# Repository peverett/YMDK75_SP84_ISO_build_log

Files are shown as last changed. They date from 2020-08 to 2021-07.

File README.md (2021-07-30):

# YMDK 75% SP84 Split Keyboard Build Log

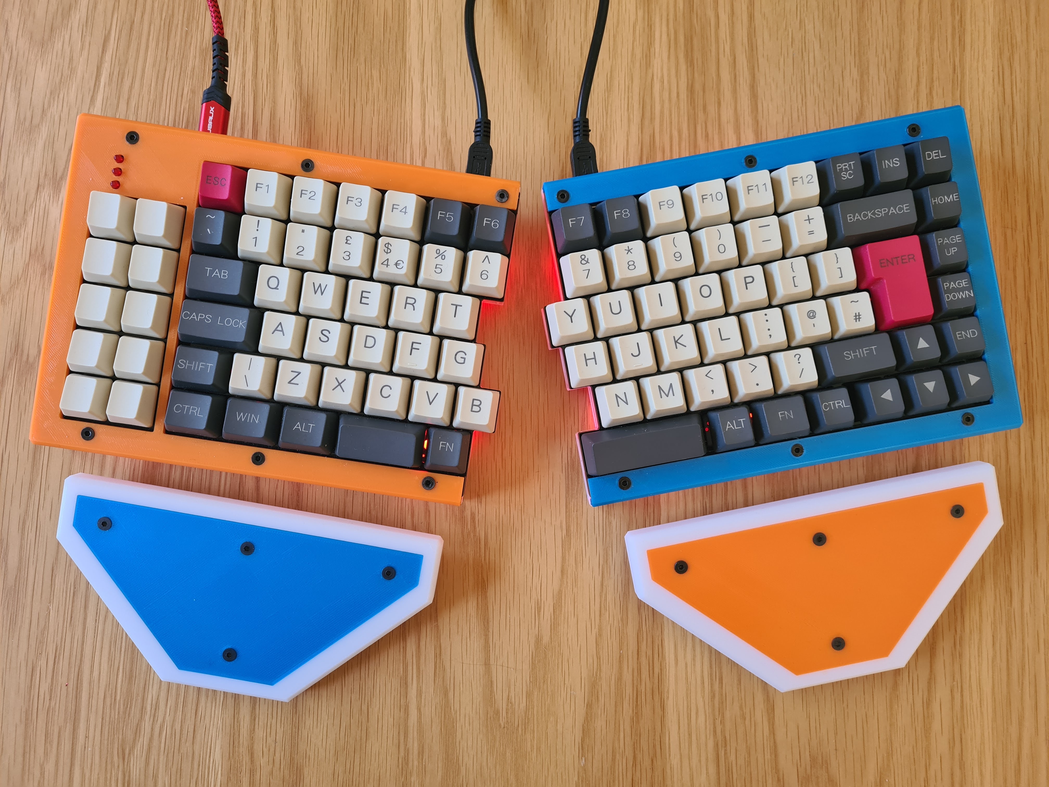
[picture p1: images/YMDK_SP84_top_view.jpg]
YMDK75-split

Final build with YMDK keycaps.

# Introduction
I decided to level up my Mechanical Keyboard skills by building my first kit.

When it comes to Mechanical Keyboards, I know what I like
* ISO UK over ANSI
* MX Browns or MX Clears

I've wanted a split keyboard for a while, but the need for an ISO UK layout put
me off a pure Ergonomic build. It's also very hard to find a custom split that 
isn't just ANSI.

The YMDK 75% Split Keyboard is similar to the V.EA layout. All images I found
on-line where ANSI layout but the specs state it can do ISO. It's also quite
in-expensive (as mechanical keyboards go), so I decided to give it a try.

Unfortunately, I didn't find any build instructions for the kit on-line and 
assumed they would come with the kit. I assumed incorrectly. Any one else
planning to build this kit, especially for ISO layout, may find this useful.

## Update: 2020-09-30
The Tai Hao ABS key caps, although very nice, didn't quite map to the keyboard 
layout, and the custom keys I received from WASD keyboards didn't blend well 
enough.

Then I found that I could buy the YMDK 96 84 key caps in Grey/Beige for ISO/ANSI
layout from Amazon UK. This set wasn't fully ISO UK, but I found the additional 
ISO keys for the YMDK set could be bought to make it a full ISO UK layout.

These key caps aren't as nice or as high quality as the Tao Hao ABS Doubleshot 
key cap set I originally bought, but they fit the layout perfectly and I am very 
happy with them.

## Custom Case Modification: 2020-12-27

The kit comes with six layers of laser cut acrylic that makes up the case, held
together with 10mm M3 screws and hexagonal brass stand-offs. However, the keyboard
underglow is very poor due to the black acrylic not reflecting the underside LED 
very well. I designed my own top and bottom layer to the each keyboard half. They
completely encapsulate the middle layers and use the same fixings to hold it 
together.

By using a white PLA for the bottom of the keyboard halves, the underglow is
significantly improved. The portal theme is almost accidental, I just used the
PLA colours I had available.

All the 3D models are in the [case_models](case_models/README.md) sub-folder for 
this repository, including some matching 3D printed wrist rests for each half.

## Parts

| Parts | Cost | Source |
|:---:|:---:|:---:|
| Split 75% SP84 DIY Kit (MX Browns) | £91.01  | AliExpress - YMDK Store |
| YMDK 96 84 ANSI ISO Keycap set (grey/beige) | £19.83  | Amazon UK |
| YMDK UK ISO Additional Keys Set (beige) | £10.45  | Amazon UK |

Some prices are converted from USD to GBP, and only accurate to the time of 
purchase.

### Split 75% SP84 DIY Kit

[Split 75% SP84 Acrylic Case Plate Underglow Fully Programmable PCB Stabilizers
ANSI ISO DIY Kit](https://www.aliexpress.com/i/33006060286.html) similar to VEA layout.
* There are several purchase options from bare PCB to fully assembled kit, with
a variety of switch options available too.
* I went with option 3 - Kit + 97 Cherry MX Brown switches + MX Stabilizers.
* You also need to buy 3 LED to go with the kit. I had some already, so
didn't bother.
* The kit doesn't include key caps but you can buy an YMDK key cap set for ANSI
and ISO, and a separate YMDK set for European ISO keys, including UK ISO.

Originally:
* [Tai Hao ABS Double Shot OEM Keycaps](https://www.aliexpress.com/item/32817770213.html) and [ISO Modifier Keycap kit](https://www.aliexpress.com/i/32962248699.html)
* Fortunately, YMDK sell the [extra keys for the SP84](https://www.aliexpress.com/item/4000873836738.html?spm=a2g0s.9042311.0.0.1a954c4d8baSSx) as a kit. Although they are only PBT, they are blank.
* The biggest issue I discovered is the right shift for ISO layout which is an R1 1x1.75 key.  
* I ended up buying the right shift and a couple of R1 1x1 keys for the bottom row from WASD. The postage was as expensive as the keys!

Updated 2020-09-30
* [YMDK 96 84 ANSI ISO Keycap set (gray/biege)](https://www.amazon.co.uk/gp/product/B079GZQFY6/ref=ppx_yo_dt_b_asin_title_o00_s00?ie=UTF8&psc=1) 
ISO layout but not quite ISO UK.
* [YMDK UK ISO Additional Keys Set (biege)](https://www.amazon.co.uk/gp/product/B086PDFN9S/ref=ppx_yo_dt_b_asin_title_o00_s00?ie=UTF8&psc=1) 
  for the missing ISO UK keys 

# Build Log

## YMDK 75% SP84 Keyboard kit.
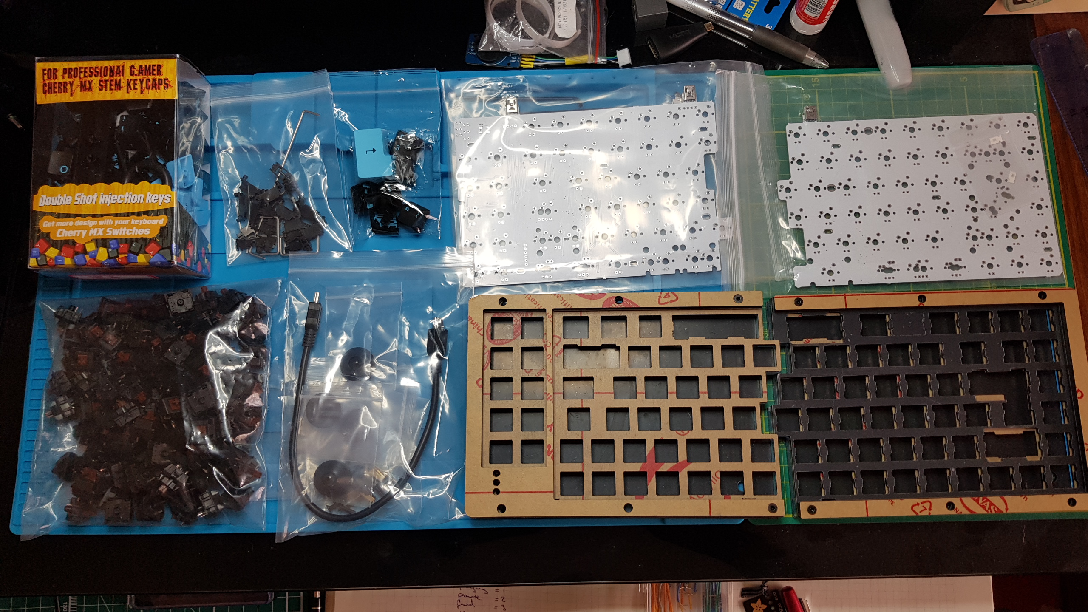
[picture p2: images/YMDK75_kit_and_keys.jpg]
Kit and Keys


The kit came in a plain box and was well protected with bubble wrap. The kit
contained:
* Two PCB boards (left and right hand side)
* The acrylic case parts, there are 6-layers to each side, with one being a 
clear acrylic layer for the under-glow.
* Fixings for the case consisting of
    * M3 10mm Countersunk hex bolts x 20 (should be 24)
    * 10mm brass standoffs female x 10 (should be 12)
* A bag of MX Stabilisers, enough for 5 stabilisers including the space-bar!
* 4 feet and bolts for feet
* USB-Standard-A to USB-Mini-B cable to connect the PC to the keyboard.
* USB-Mini-B to USB-Mini-B to connect the two keyboard halves.
* 96 x Cherry MX Brown switches.

Note: 
* The kit was missing 4-bolts and 2-standoffs for the case, but 
2-days after delivery they came in the post in a little box. 
* The kit doesn't include indicator LED, 3 are needed, I already had some but 
the YMDK shop has links to appropriate LED.
* The kit comes with 96 switches, which is the exact amount needed for the ISO 
layout.

## Testing the PCB

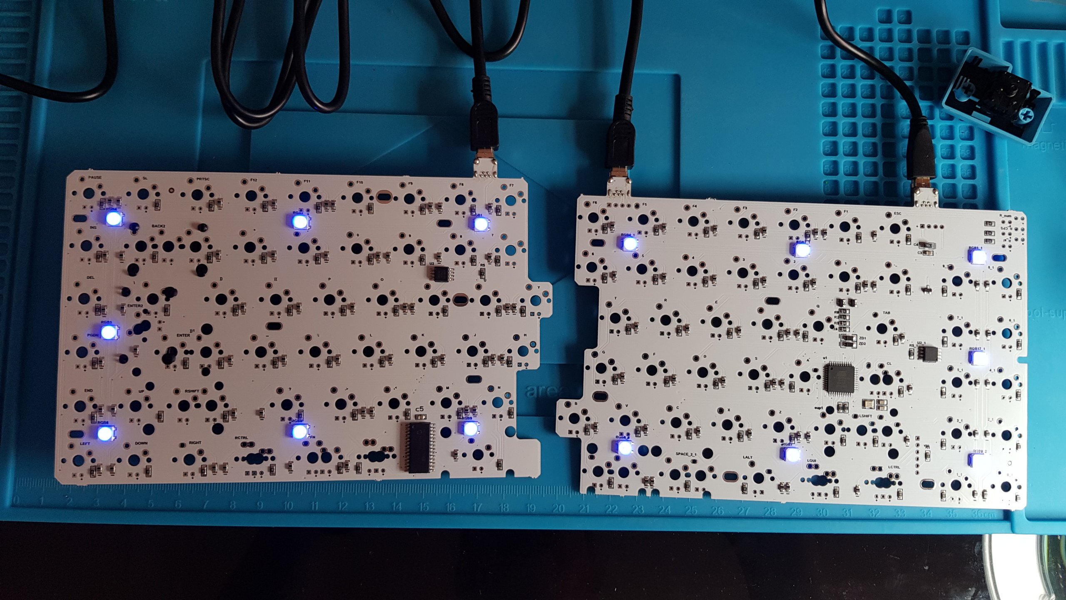
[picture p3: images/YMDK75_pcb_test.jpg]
pcb_test


Before starting I connected the PCB using the USB cables, you can see the 
under-glow LEDs are working.

## Right Side Stabilisers
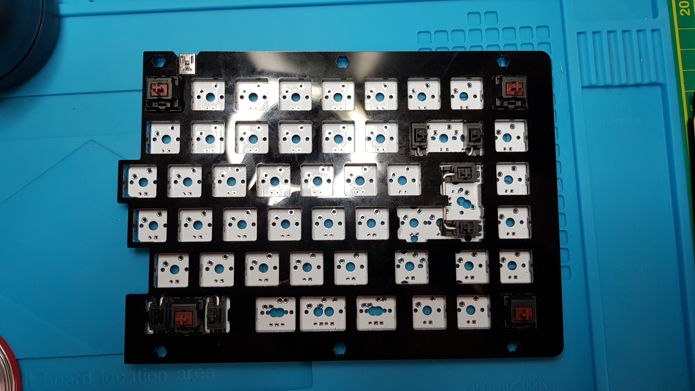
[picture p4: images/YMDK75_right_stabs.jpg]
right_side_stabs


Here you can see the Right side part of the keyboard with the Backspace, Return
and right side split Space-bar stabilisers. These are standard MX stabs.

* You have to fit the stabilisers before soldering any of the switches because the 
switches fit to the plate and hold the PCB in place.
* Three are needed, all the same size, even for the left side split space-bar key.
* The space-bar key stabiliser has to be fitted 'upside down' because it is at the
edge of the PCB and there isn't a full whole for the stabiliser leg. 
* I should have taken a picture before adding the base plate and four corner switches. I did for the left side though, so go see that.
* The right side shift is 1.75u, even for the ANSI layout. Let me tell you, that is a bugger to find a key cap for! 
(Updated 2020-09-30: Unless you buy the YMDK key cap set).

## Left Side Stabilisers

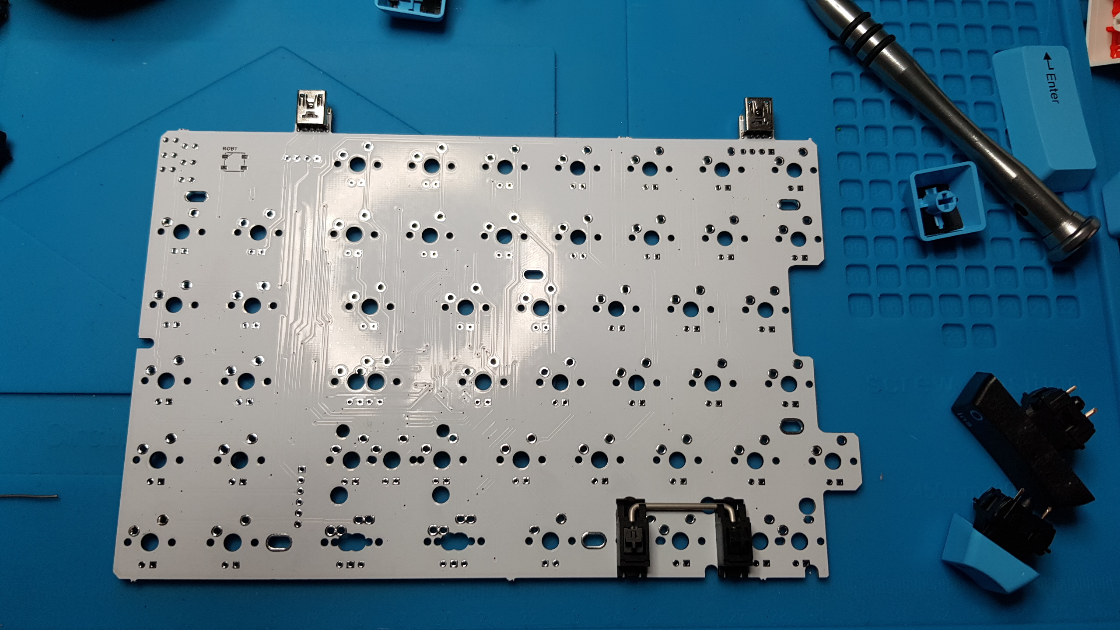
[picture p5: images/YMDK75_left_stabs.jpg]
left_side_stabs


I remembered to take the picture BEFORE fitting the plate and corner switches.
You can more clearly see the space-bar stabiliser is fitted upside down because it
is on the edge of the PCB. You can see, staggered to the right, two half-hole/notches, if you wanted the split further right. 

Because this is an ISO layout, no other stabilisers are necessary. 

## Left Side ISO keys
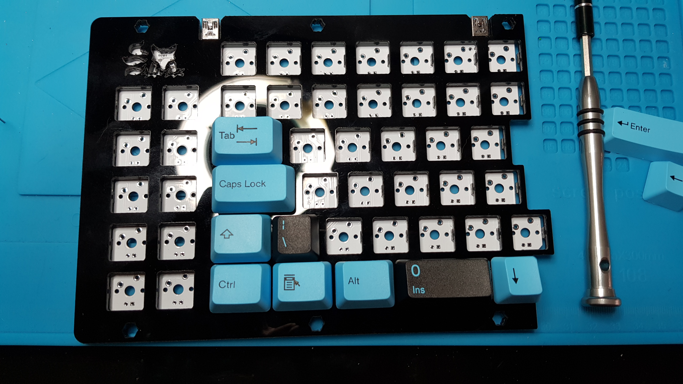
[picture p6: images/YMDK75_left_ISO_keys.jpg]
left_ISO_keys


Before soldering anything, I laid out the switches with the ISO keys to get 
the correct positions. 

As you can see the [0 Ins] key from the number-pad is the correct size for the
left size space key. I will replace it later when I get the keys from YMDK.

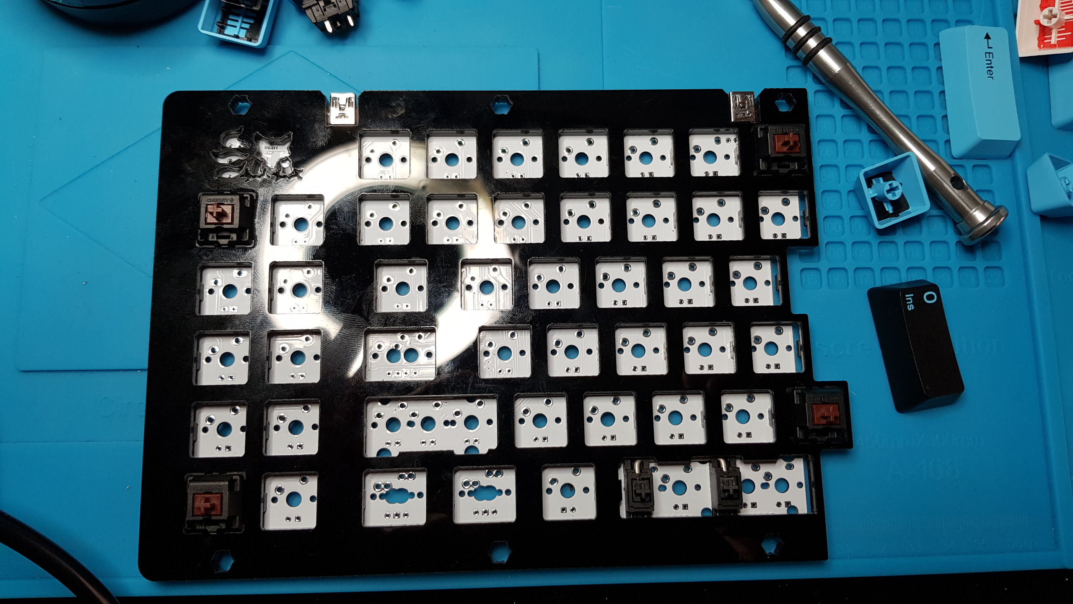
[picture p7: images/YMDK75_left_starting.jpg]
left_starting


As with the right side, two layers of acrylic make up the switch plate. The
switches fit tightly and click into each switch hole. Then, when soldered to
the PCB , the switched hold the plate to the PCB. There are no mounting screws
or holes in the PCB for this otherwise.

Following other guides, I soldered the corner switches first and then filled it
in. 

You can probably already see that the acrylic is a finger-print magnet.

## Fully Soldered and Naked

Here are the left and right side fully soldered and naked (without key caps), so
that you can clearly see the switch placement for the ISO layout. 

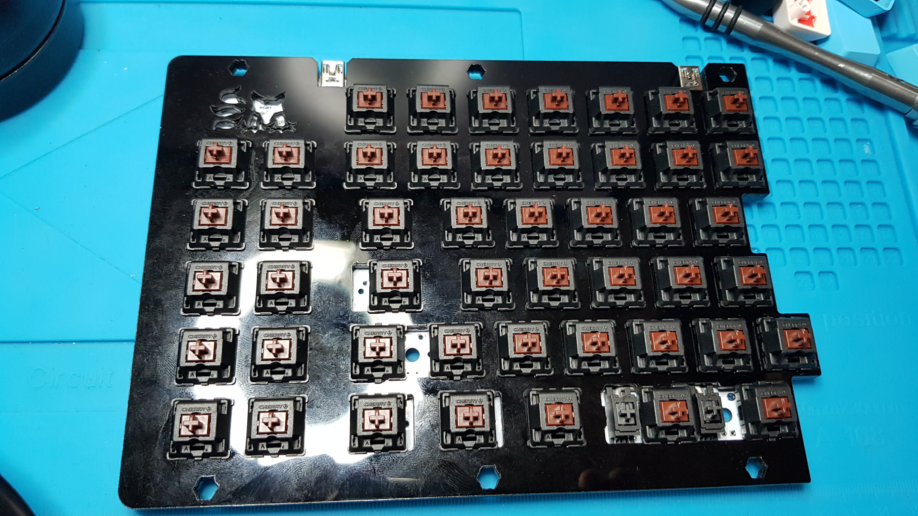
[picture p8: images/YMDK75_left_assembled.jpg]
left_assembled


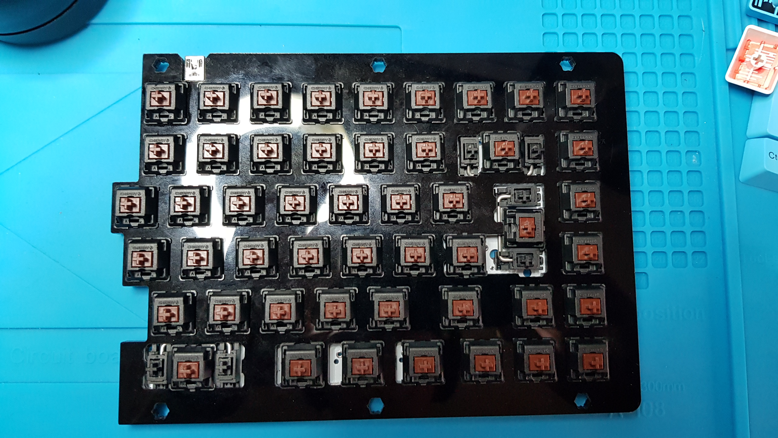
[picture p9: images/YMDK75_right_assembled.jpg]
right_assembled


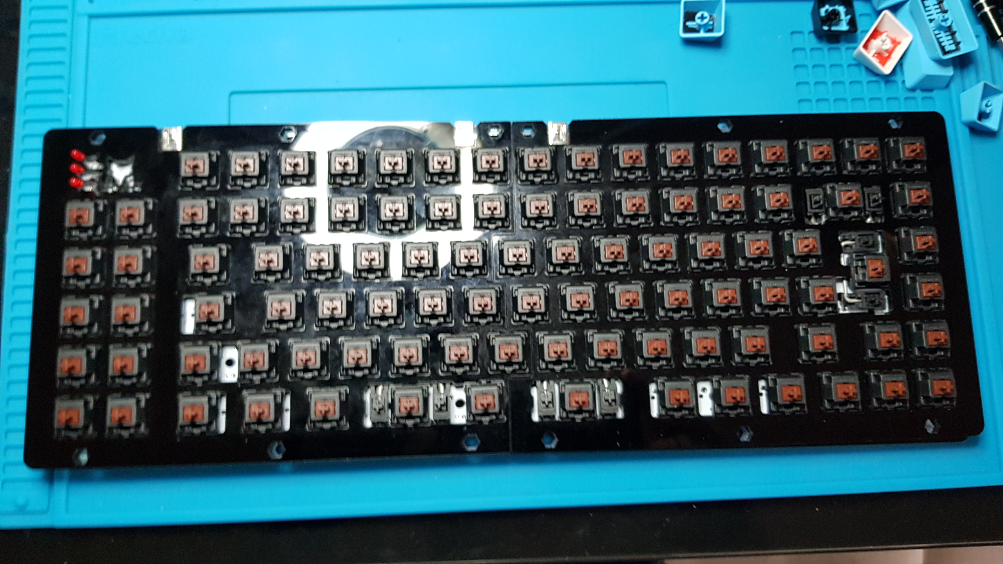
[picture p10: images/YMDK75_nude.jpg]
full_nude


## Fully Assembled

Here it is with all key caps in position. You can see that I have used some of
the num-pad keys on the bottom row for the split space-bar and R1 keys.

~~I'll add updates once the YMDK spare key kit comes.~~ In the end, I bought
the YMDK key cap set for this keyboard (see top picture).

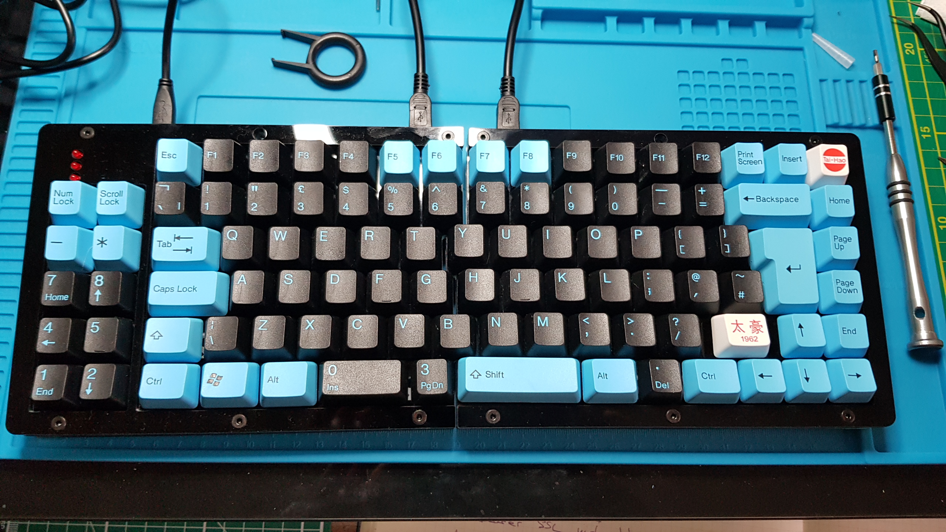
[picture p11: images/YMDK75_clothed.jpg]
fully_assembled


## Keyboard Layout 

Because, I've bastardized some of the keypad keys and because the documentation
is lacking, here are some layout diagrams for the YMDK 75% SP84 in ISO configuration.

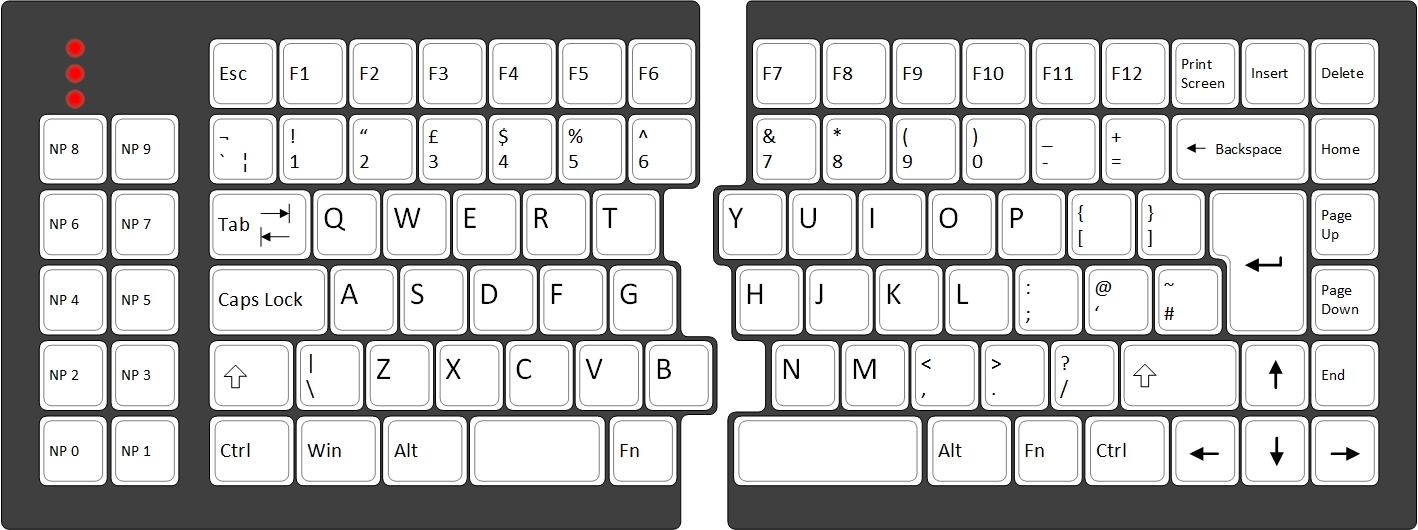
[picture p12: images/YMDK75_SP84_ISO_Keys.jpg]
ISO_Keys

Note that the extra keys on the left side are actually mapped to what would be
the numberpad on a full size keyboard. The numlock will change their function
but the standard keyboard software configuration doesn't map a numlock key.

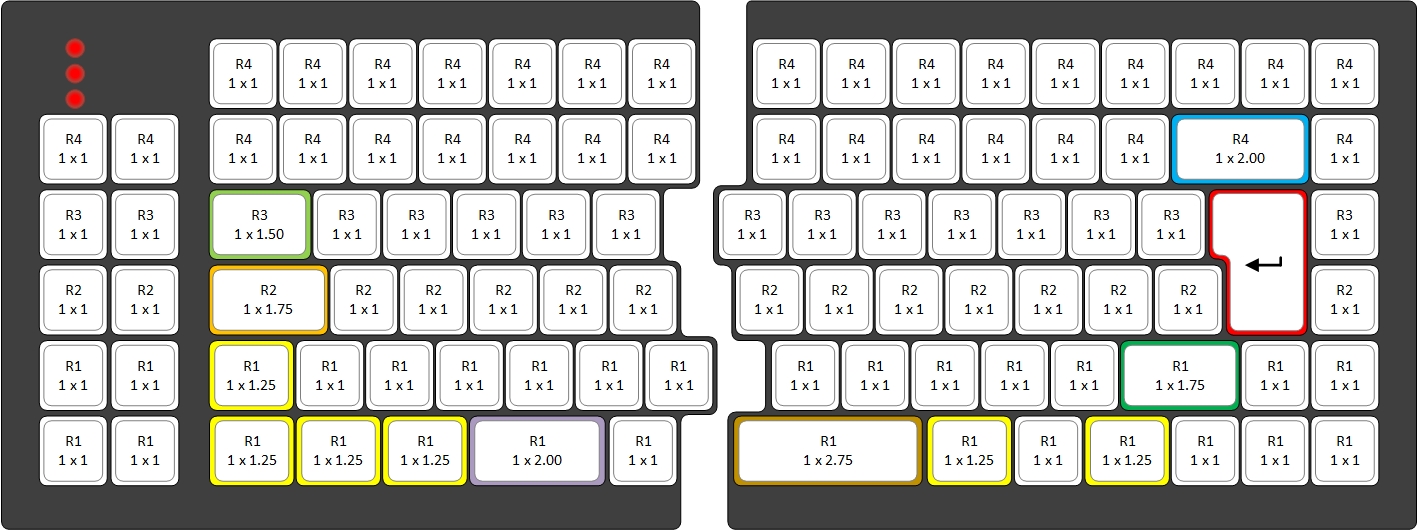
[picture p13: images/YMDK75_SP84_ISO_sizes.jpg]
ISO_Sizes

This is the same diagram but with the OEM key cap sizes. As previously stated 
that R1 1 x 1.75u Right Shift key is the hard one to source.

# Programming the Keyboard
I used the [Bootmapper Client](https://www.dropbox.com/s/3bn9flirkb49ahz/BootmapperClient.zip?dl=0)
application (downloaded from DropBox).

The software is little unpolished but serviceable.

I found two really good guides, linked below
* Drop - [Programming KBD Keyboards via Bootmapper Client](https://drop.com/talk/1392/programming-kbd-keyboards-via-bootmapper-client-tmk-guide-getting-added-soon-here)
* MecKey Alpha - [Guide on Bootmapper client](https://meckeyalpha.com/pages/guide-on-bootmapper-client)

# Conclusions

Overall, I am very happy with this keyboard and I am using it as my daily driver.
The cons listed below are minor, in my opinion. 

## Pros

* The kit was relatively inexpensive.
* It was a fun build for me, as the first keyboard I've built.
* I love the layout and using the split is very comfortable.
* Surprisingly, the multi-layered cut acrylic makes for a very solid, weighty 
keyboard.

## Cons
* Kit came with everything except key caps and three LEDs, but I feel that it could
have included the LEDs. 
* The acrylic is an absolute finger-print magnet.
* ~~YMDK sell key-cap sets (2 different colour schemes) for this, but not ISO~~.
* ~~The under-glow is very dim and can't be seen in normal lighting conditions.~~

## Update 2020-09-30: 

As you can see, some of the Cons turned out to be simple to resolve.
* The under-glow is configurable using the Bootmapper Client software, but by 
default is very dim.
* YMDK key caps for ISO and ANSI are available on Amazon UK, but it's not a full 
ISO UK set. There are additional YMDK ISO keys for the key caps that achieve a 
full ISO UK layout and I am very happy with that.

## Update 2020-11-09:

3D printing a case with a white translucent bottom half seems to significantly 
improve the underglow.

## Update 2020-12-27:

I completed the 3D printed case modifications, including wrist rests and added 
the 3D model files in this repository. See the [case_models](case_models/README.md)
folder for more details.

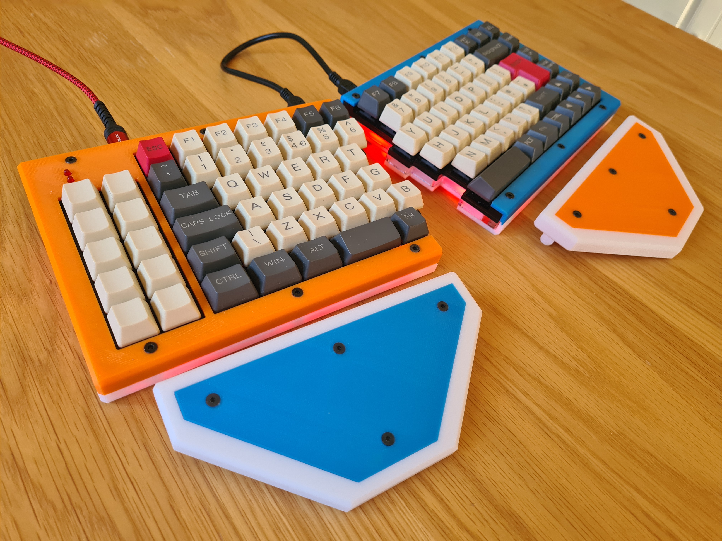
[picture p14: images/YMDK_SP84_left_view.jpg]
YMDK75-split

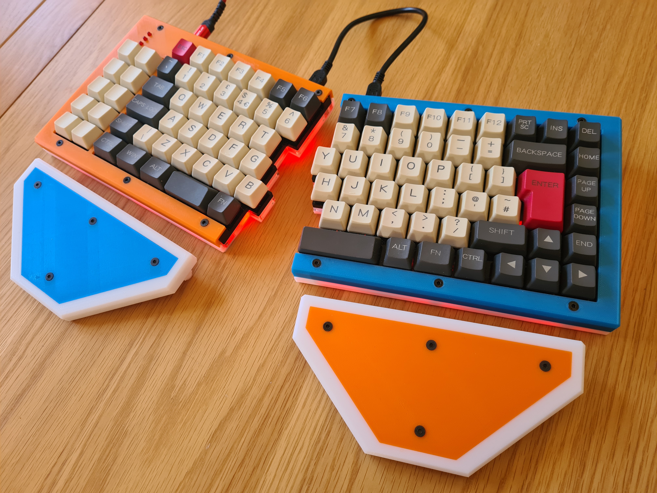
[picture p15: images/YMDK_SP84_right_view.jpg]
YMDK75-split


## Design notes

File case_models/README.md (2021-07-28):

# YMDK 75% SP84 Split Keyboard 3D Case Models

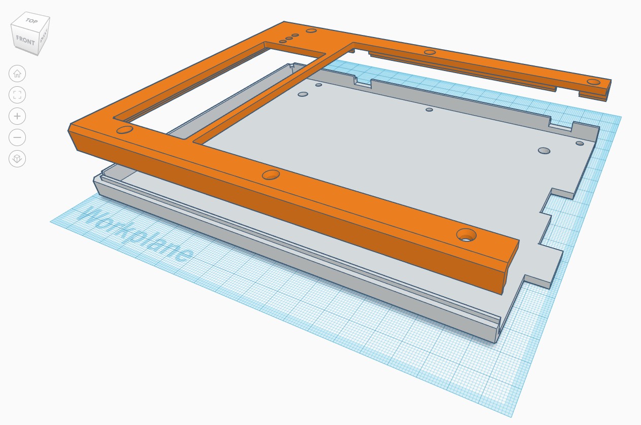
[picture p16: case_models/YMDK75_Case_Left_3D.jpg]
YMDK_3D_left

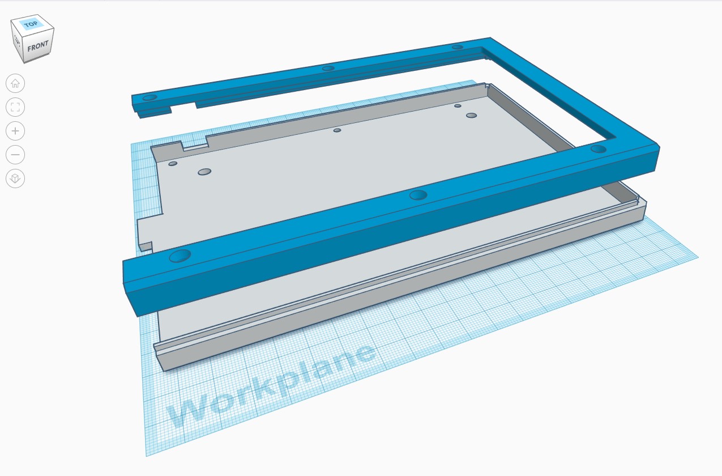
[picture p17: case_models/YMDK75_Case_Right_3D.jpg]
YMDK_3D_right


I used [TinkerCad](https://www.tinkercad.com) to design the case and wrist rest models, 
for a free, on-line 3D modeling tool it's basic but it gets the job done.

I have a Prusa MK3S Printer, and used the PrusaSlicer software to slice the models
for printing. 

### UPDATE: 2021-07-28
Added .SVG files for the keyboard case tops and bottoms.

## Print Settings

For printing, I used the basic default settings.

| Setting | Value |
|---|---|
| Print Setting | 0.15mm QUALITY MK3 |
| Filament | Prusa PLA |
| Printer | Original Prusa i3 MK3s  |
| Supports | None |
| Infil | 15% |

## Sliced Info

| Model | Print Time | Filament (g) | Filament (m) |
|:---:|:---:|:---:|:---:|
| Wrist-Rest-bottom.stl | 3h 59m 17s | 43.05 | 14.43 |
| Wrist-Rest-foot.stl | 41m 52s | 6.10 | 2.05 |
| Wrist-Rest-top.stl | 1h 22m 44s | 18.37 | 6.16 |
| YMDK-SP84-left-bottom.stl | 6h 14m 41s | 79.59 | 26.69 |
| YMDK-SP84-left-top.stl | 3h 17m 8s  | 29.73 | 9.97 |
| YMDK-SP84-right-bottom.stl | 6h 15m 48s | 80.13 | 26.87 |
| YMDK-SP84-right-top.stl | 3h 1m 26s  | 26.55 | 8.90 |

Don't forget to double up when printing the wrist wrest parts!

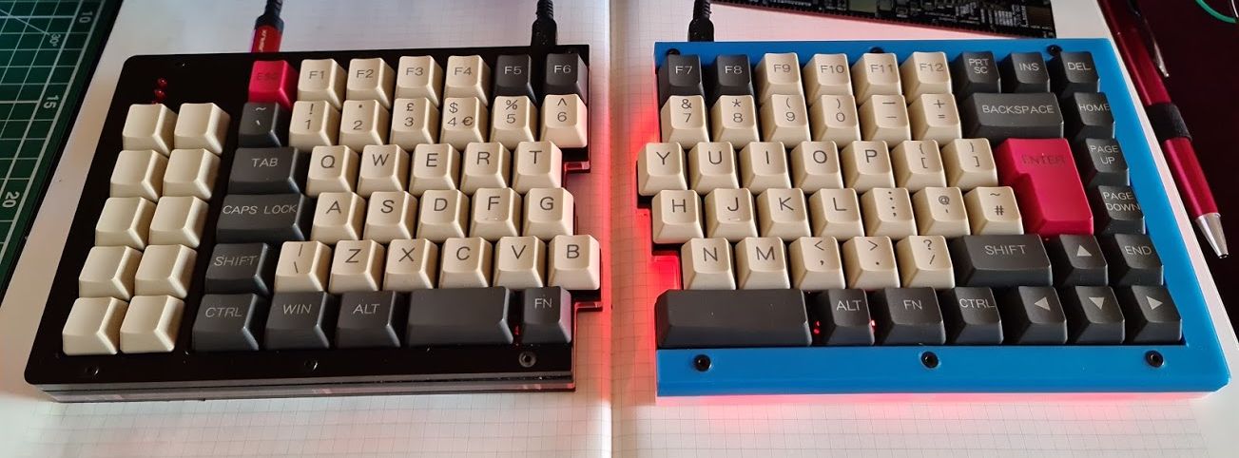
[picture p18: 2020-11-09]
images/YMDK_SP84_3d_case_comparison.jpg

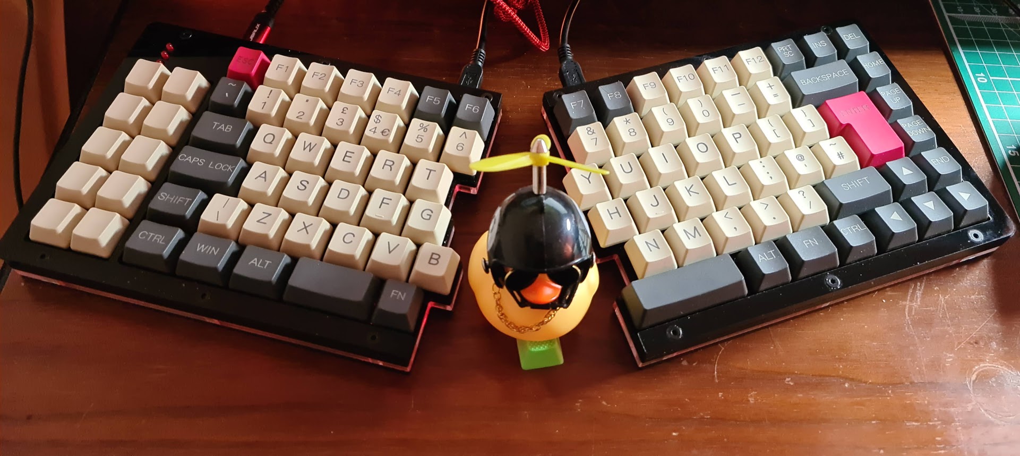
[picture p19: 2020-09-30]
images/YMDK_SP84_ISO.jpg

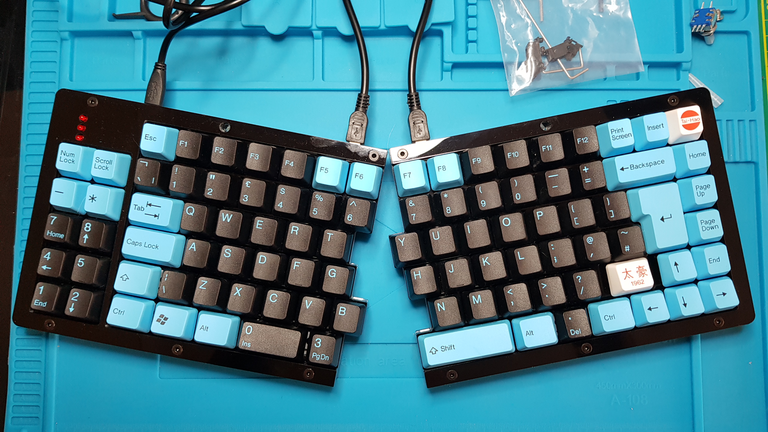
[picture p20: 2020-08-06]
images/YMDK75_split.jpg

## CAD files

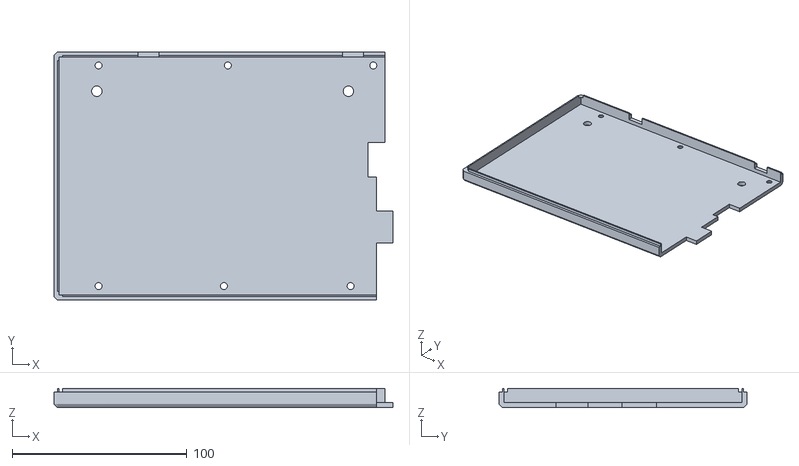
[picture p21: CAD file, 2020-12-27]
case_models/YMDK-SP84-left-bottom.stl
194.0 x 142.0 x 11.0

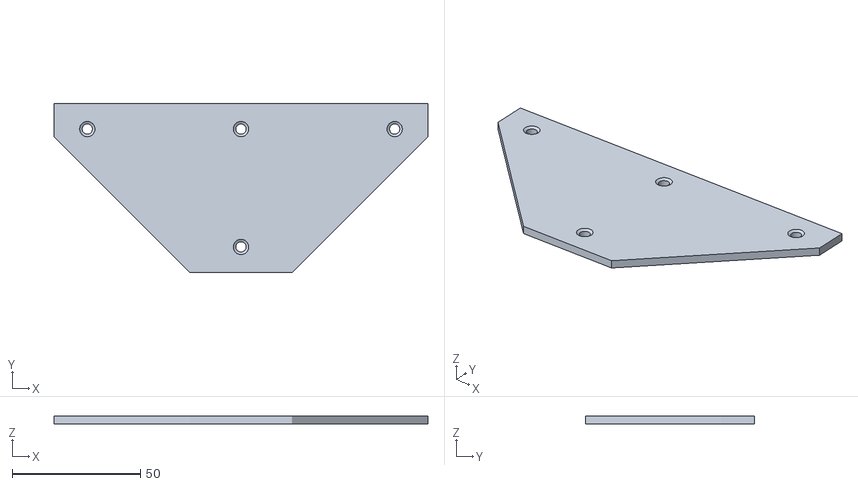
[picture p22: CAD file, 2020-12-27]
case_models/Wrist-Rest-top.stl
146.0 x 66.0 x 3.00

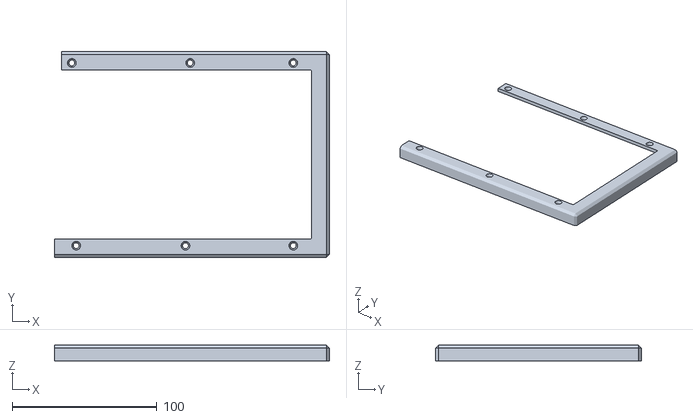
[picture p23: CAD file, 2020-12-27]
case_models/YMDK-SP84-right-top.stl
190.0 x 142.0 x 10.9

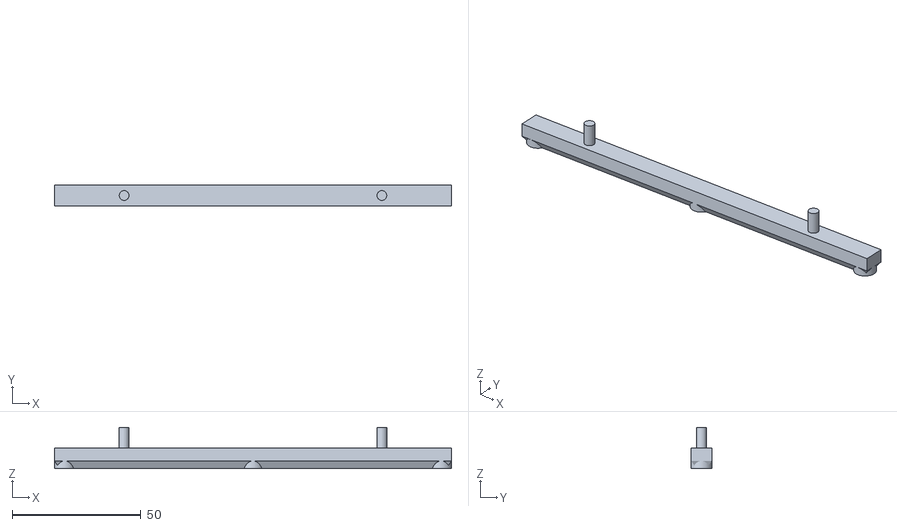
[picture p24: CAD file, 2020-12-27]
case_models/Wrist-Rest-foot.stl
154.0 x 8.00 x 16.0

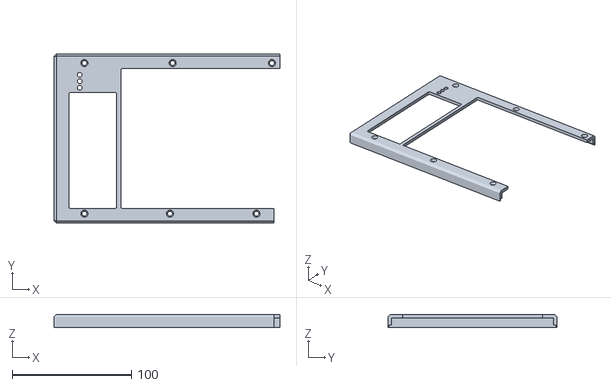
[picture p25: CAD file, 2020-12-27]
case_models/YMDK-SP84-left-top.stl
189.5 x 142.0 x 10.9

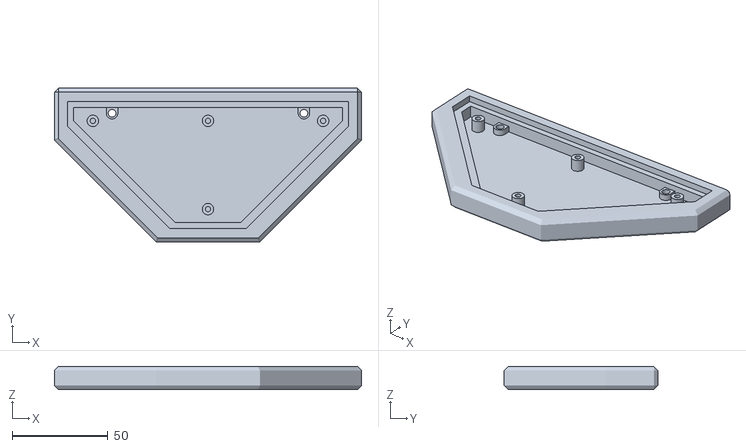
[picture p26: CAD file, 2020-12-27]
case_models/Wrist-Rest-bottom.stl
160.0 x 80.0 x 12.0

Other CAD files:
case_models/YMDK-SP84-right-bottom.stl

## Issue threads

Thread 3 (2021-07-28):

Provide CAD files

woelper, 2021-07-28:
Hello and many thanks for the super helpful build log. It inspired me to print my own plates (or possibly have them cut from carbon). However, I plan on doing individual layers still and would be super happy if you could provide/export the CAD files used to make the STLs so I can create a template for a layer from them. Would this be possible?

Thanks in advance!

peverett, 2021-07-28:
Hi, I used Tinkercad (an on-line 3D CAD tool - Basic but versatile) - As well as the STL files I put in the report, I can export the models as:

- OBJ
- GLTF
- SVG - for Laser cutting.

Maybe the last format is the most useful for you, please let me know I and I will those files to the repo.

woelper, 2021-07-28:
SVG would be brilliant! Thanks for looking into this!

peverett, 2021-07-28:
I've added the SVG files to https://github.com/peverett/YMDK75_SP84_ISO_build_log/tree/master/case_models

Hope they work for you!

woelper, 2021-07-29:
Thank you so much!
Both bottom halves work, but unfortunately, the top SVGs are empty (you can tell by looking at the source). Would those be possible to export? Otherwise I'll try reverse engineering something with the bottom layouts.

Thanks!

peverett, 2021-07-29:
It might be because, to get a better screen shot, the top part of the case is 'floating' above the work space Z plan. When I export other formats, that doesn't seem to be a problem. This evening, when I have time, I will go into Tinkercad, move them to the workplane (0 Z axis) and export again, and this time, I'll check the file size.

peverett, 2021-07-30:
I have put the top case models on the Z plane (flat side down) and re-exported them. Please try and see if the updated SVG files work better for you...
- YMDK-SP84-left-top.svg
- YMDK-SP84-right-top.svg

woelper, 2021-07-30:
Looks perfect, you are the best!

peverett, 2021-07-30:
If you have time, please let me know how your project turns out (or post to r/mechanicalkeyboards on reddit :)

Closed 2021-07-30.

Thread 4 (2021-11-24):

Could you share your Layout config?

meteozond, 2021-11-24:
Hello, you've made awesome built.

[Looks like you've made your own layout configuration](https://github.com/peverett/YMDK75_SP84_ISO_build_log#keyboard-layout), could you share it?

I've just built my own sp84 with hotswaps and found that switches sit too loose in original frame holes.
So I'm thinking of printing my own switches frame and existing config could extremely simply my work.

meteozond, 2021-11-25:
I've finally managed to draft layout

- [left](http://www.keyboard-layout-editor.com/#/gists/c32946fa4b6e3d9fec0e4d1c67cbd649)
- [right](http://www.keyboard-layout-editor.com/#/gists/33730a57e0b35df9d58da662283ce3a9)

peverett, 2021-11-25:
Hi, I assume you are talking about the layout that you can define in  the Bootmapper Client application?
I can't currently share my mapping (because my Keyboard is at work and I am working from home) but I didn't change the default mapping except for the ISO layout.
If I ever get back into the office, I will try and download my config and add to the repo.

Closed 2021-12-08.

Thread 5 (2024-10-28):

bootmapper update problem

jun0-ds, 2024-10-28:
Hi, thanks for your content

My insert key works as a home key, so i tried to update the firmware with ps2avrGB_firmware_V1.5.0_190822.

But it crushed. I'm finding a way to reset the pcb plate.

Do you how to reset the pcb plate?

jun0-ds, 2024-10-29:
Thanks for answering.

Closed 2024-10-29.

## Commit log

2020-11-09 Updated for 3D case design in progress.
2020-12-27 Updated with 3D printed case modification, images and models.
    [Wrist-Rest-bottom.stl, Wrist-Rest-foot.stl, Wrist-Rest-top.stl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]
2020-12-27 Updated the main README.md for the 3D Case mod.
2021-07-28 Added .SVG file for case models
